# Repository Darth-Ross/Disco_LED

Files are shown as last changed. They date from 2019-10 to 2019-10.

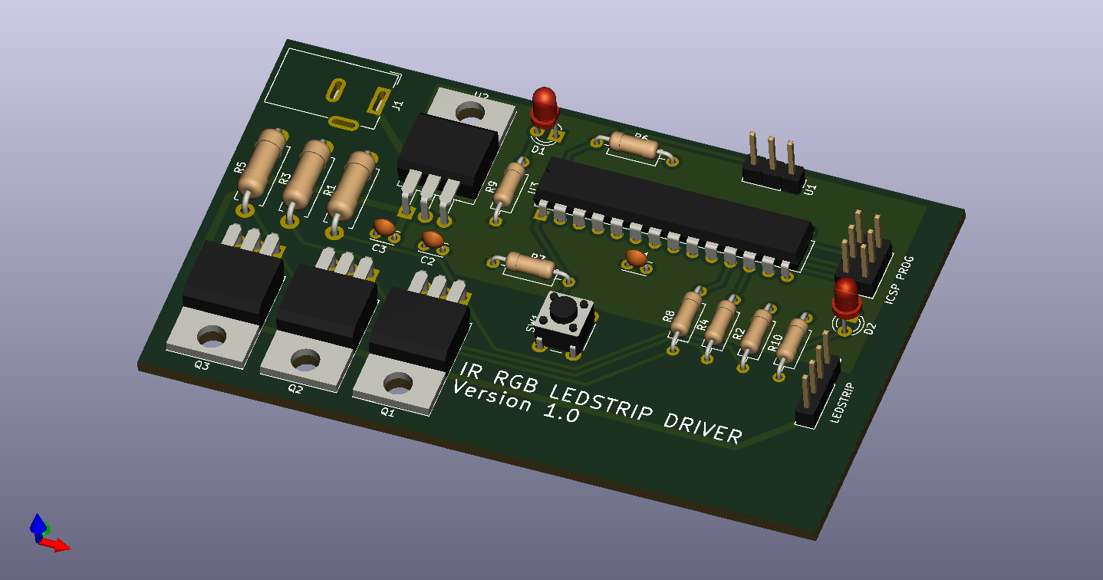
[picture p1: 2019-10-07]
Hardware/PCB/Renders/PCB_RENDER_ISOMETRIC.png

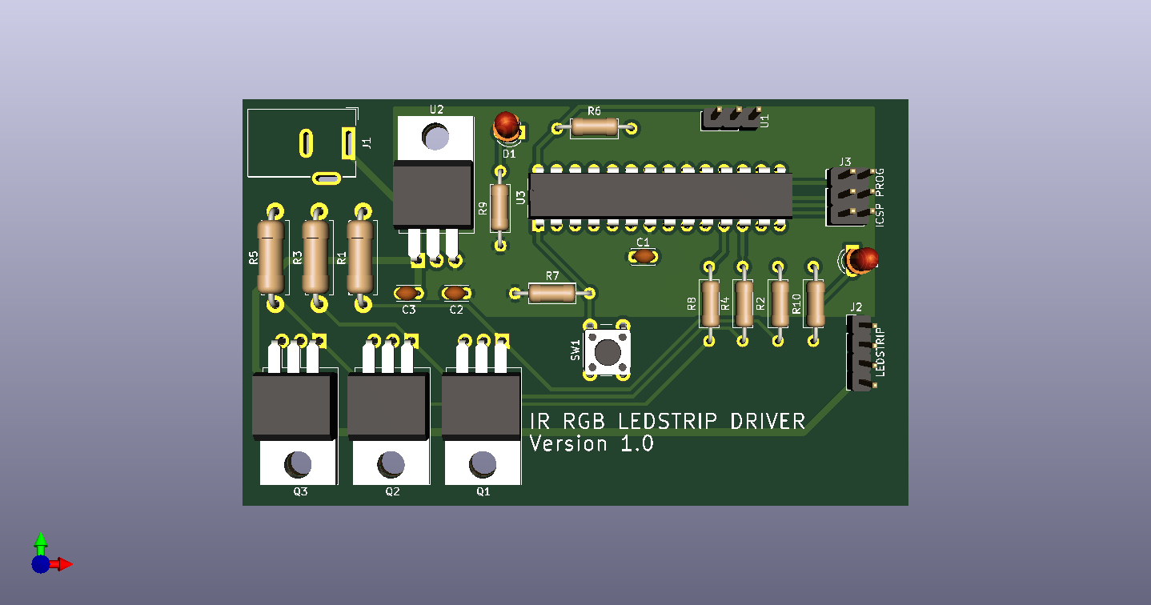
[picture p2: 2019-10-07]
Hardware/PCB/Renders/PCB_RENDER_TOP.png

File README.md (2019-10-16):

# Quick description 

This is a design for a IR RGB LEDstrip driver which uses a 24 key RGB remote. It can display 16 predetermined static colours, change brightness, turn off and on again while remembering the last colour and display special functions like for example smooth colour change or colour flashing. 

The repo includes both hardware and software design which you can either use directly or include in your own projects.

# Licenses

The software is licensed under the GNU General Public License V3.0 and the hardware is licensed under the CERN Open Hardware License V1.2. See the license files in each folder for more information.

# Libraries 

These are all the libraries I have used that were made by other users.
- https://github.com/electrobs/AVR-LIBRARY-IR_REMOTE_RECV

# Hardware changelog
#### V1.0
- Added electrical schematic
- Added PCB design
- Added licensing
#### V1.0.1
- Added gerber files 
- Added 3D renders 
#### V1.1
- Fixed connection error for ICSP port

# Software changelog
#### V1.0
- Basic feature implementation
- Added 24 key RGB remote support
- Added ATmega328p support
- Added licensing
#### V1.1
- Added first implementation of CMD_REPEAT functionality
- Reworked the brightness system to use percentage instead of RGB values. 

#### Known bugs
- CMD_REPEAT remembers the command BPLUS OR BMIN even after pressing other commands. This will cause the BPLUS or BMIN command to be executed if other commands are repeated.

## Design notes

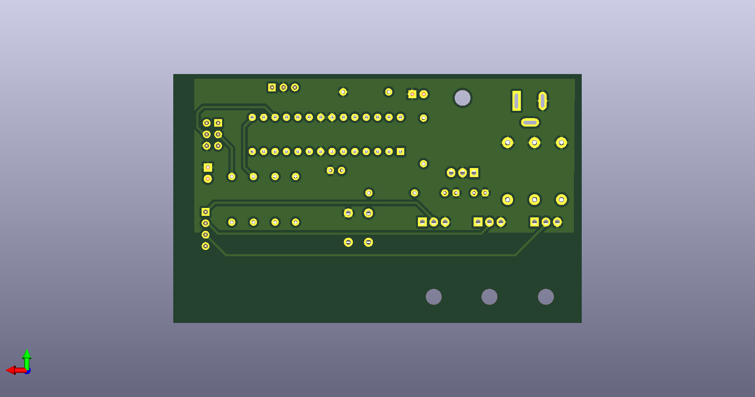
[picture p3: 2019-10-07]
Hardware/PCB/Renders/PCB_RENDER_BOTTOM.png

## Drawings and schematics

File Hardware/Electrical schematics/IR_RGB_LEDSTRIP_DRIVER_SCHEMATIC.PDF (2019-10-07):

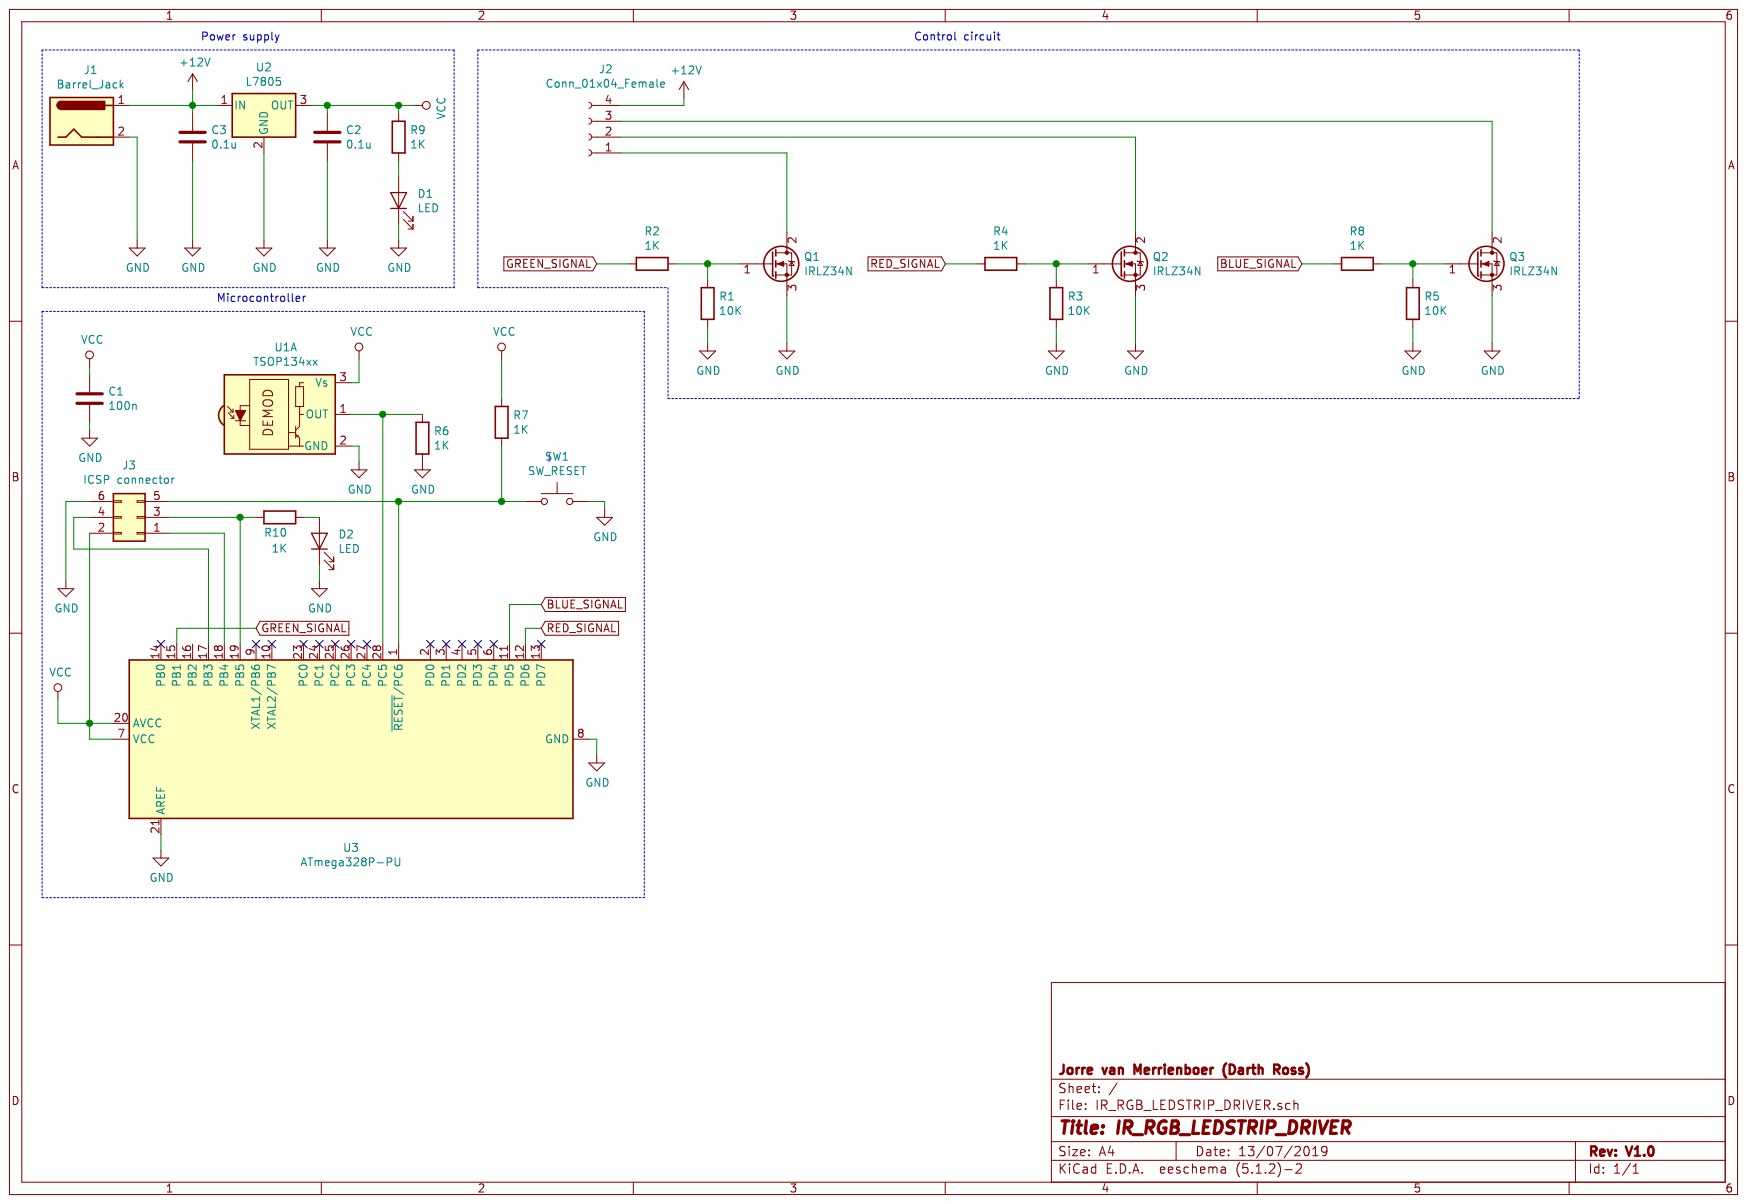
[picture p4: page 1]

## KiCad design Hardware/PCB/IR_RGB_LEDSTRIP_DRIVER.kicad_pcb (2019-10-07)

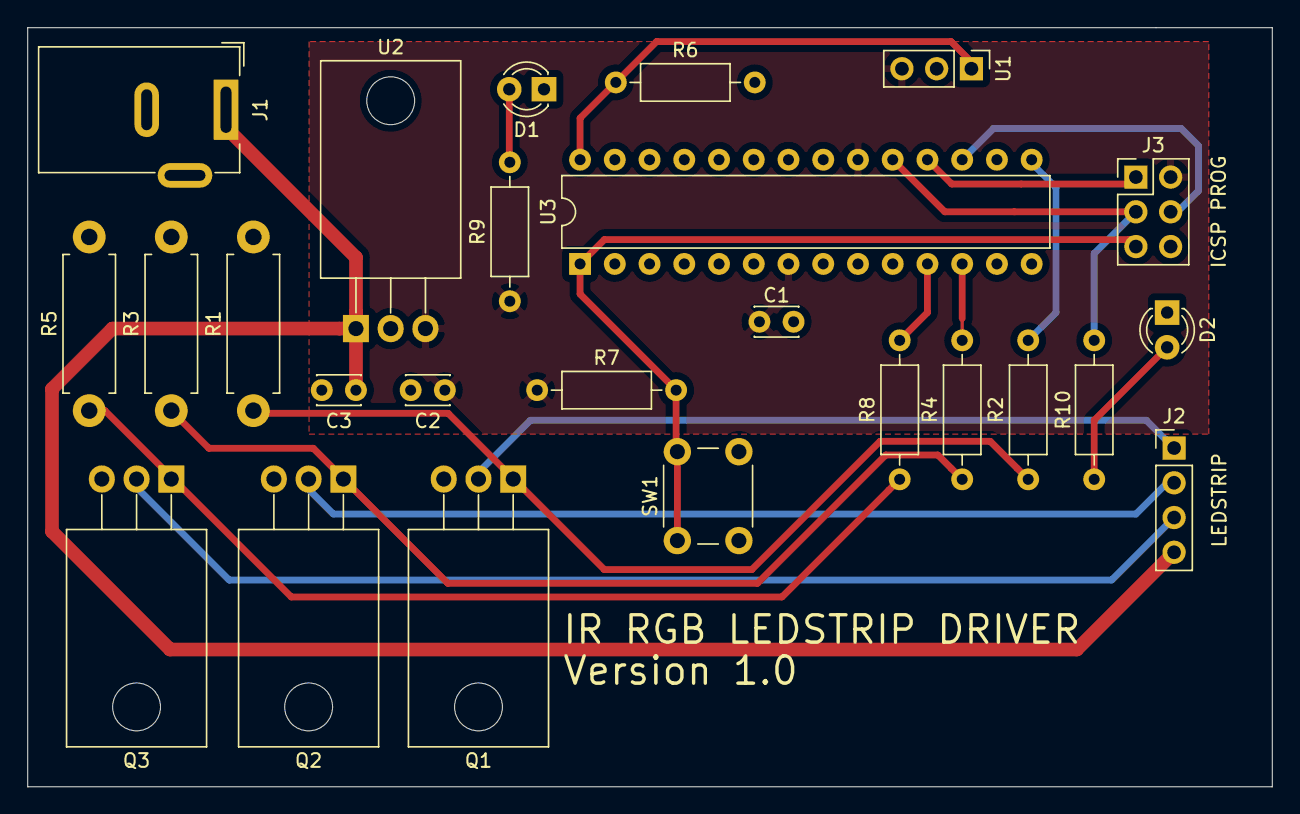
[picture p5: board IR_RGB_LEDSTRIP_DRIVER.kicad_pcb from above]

Board: 2 copper layers, 91.0 x 55.5 mm, 25 parts (0 on the bottom side), 19 nets.

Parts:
C1: 100n; C_Disc_D3.0mm_W2.0mm_P2.50mm
C2, C3: 0.1u; C_Disc_D3.0mm_W2.0mm_P2.50mm
D1, D2: LED; LED_D3.0mm
J1: Barrel_Jack; BarrelJack_Wuerth_6941xx301002
J2: Conn_01x04_Female; PinHeader_1x04_P2.54mm_Vertical
J3: ICSP connector; PinHeader_2x03_P2.54mm_Vertical
Q1, Q2, Q3: IRLZ34N; TO-220-3_Horizontal_TabDown
R1, R3, R5: 10K; R_Axial_DIN0411_L9.9mm_D3.6mm_P12.70mm_Horizontal
R2, R4, R6, R7, R8, R9, R10: 1K; R_Axial_DIN0207_L6.3mm_D2.5mm_P10.16mm_Horizontal
SW1: SW_RESET; SW_PUSH_6mm_H5mm
U1: TSOP134xx; PinHeader_1x03_P2.54mm_Vertical
U2: L7805; TO-220-3_Horizontal_TabDown
U3: ATmega328P-PU; DIP-28_W7.62mm

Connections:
+12V: C3.1, J1.1, J2.4, U2.1
BLUE_SIGNAL: R8.2, U3.11
GND: C1.2, C2.2, C3.2, D1.1, D2.1, J1.2, J3.6, Q1.3, Q2.3, Q3.3, R1.2, R3.2, R5.2, R6.2, SW1.2, U1.2, U2.2, U3.8, U3.21, U3.22
GREEN_SIGNAL: R2.2, U3.15
unnamed: D1.2, R9.2
unnamed: D2.2, R10.2
unnamed: J2.1, Q1.2
unnamed: J2.2, Q2.2
unnamed: J2.3, Q3.2
unnamed: J3.1, U3.18
unnamed: J3.3, R10.1, U3.19
unnamed: J3.4, U3.17
unnamed: J3.5, R7.2, SW1.1, U3.1
unnamed: Q1.1, R1.1, R2.1
unnamed: Q2.1, R3.1, R4.1
unnamed: Q3.1, R5.1, R8.1
unnamed: R6.1, U1.1, U3.28
RED_SIGNAL: R4.2, U3.12
VCC: C1.1, C2.1, J3.2, R7.1, R9.1, U1.3, U2.3, U3.7, U3.20

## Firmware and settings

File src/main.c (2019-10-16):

/*
* prototype.c
*
* Created: 21-2-2018 20:30:53
*  Author: Jorre
*/

#define F_CPU 8000000UL

//AVR-libraries
#include <avr/io.h>
#include <avr/interrupt.h>
#include <util/delay.h>

//Function-libraries
#include <disco_functions.h>
#include <irremote.h>
#include <remotes.h>
#include <commonTimer.h>

int main(void) 
{
	initialiseATmega328P();
	initIR(5, RGB_REMOTE_ADDRESS, RGB_REMOTE);
	init100usTimer2(F_CPU);
	
	commandAction command = NO_ACTION;
	
	brightness_Percentage = 100;
	
	red_Value = 0;
	green_Value = 0;
	blue_Value = 0;
	
	while(1) 
	{							
		command = getIRCommandRec();
		executeCommand(command);
		displayRGB(red_Value, green_Value, blue_Value);	
	}
	
	return 1;
} 

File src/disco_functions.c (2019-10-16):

/*
 * Disco_Functions.c
 *
 * Created: 30-1-2018 1:33:41
 *  Author: Jorre van Merrienboer
 */ 

#define F_CPU 8000000UL

// AVR-libraries
#include <avr/io.h>
#include <avr/common.h>
#include <util/delay.h>

// Function-libraries
#include <disco_functions.h>
#include <irremote.h>


void initialiseATmega328P(void)
{
	/////////
	// I/0 //
	/////////

	DDRD = 0xFF;				// Set PORT D as output
	DDRB = 0xFF;				// Set PORT B as output
	
	PORTD = 0;					// Set PORT D to 0
	PORTB = 0;					// Set PORT B to 0

	/////////////
	// Timer 0 //
	/////////////

	/* Set waveform generation mode to fast PWM */
	TCCR0A |= (1 << 0);			// Set WGM00 to 1
	TCCR0A |= (1 << 1);			// Set WGM01 to 1
	TCCR0B &= ~(1 << 3);		// Set WGM02 to 0
	
	/* Set compare output mode A to inverting */
	TCCR0A |= (1 << 6);			// Set COM0A0 to 1
	TCCR0A |= (1 << 7);			// Set COM0A1 to 1
	
	/* Set compare output mode B to inverting */
	TCCR0A |= (1 << 4);			// Set COM0B0 to 1
	TCCR0A |= (1 << 5);			// Set COM0B1 to 1
	
	/* Setting prescaler to 64, PWM frequency is around 1kHz */
	TCCR0B |= (1 << 0);			// Set CS00 to 1
	TCCR0B |= (1 << 1);			// Set CS01 to 1
	TCCR0B &= ~(1 << 2);		// Set CS02 to 0
	
	/////////////
	// Timer 1 //
	/////////////
	
	/* Set waveform generation mode to fast PWM 8 bit */
	TCCR1A |= (1 << 0);			// Set WGM10 to 1
	TCCR1A &= ~(1 << 1);		// Set WGM11 to 0
	
	TCCR1B |= (1 << 3);			// Set WGM12 to 1
	TCCR1B &= ~(1 << 4);		// Set WGM13 to 0
	
	/* Set compare output mode A to inverting */
	TCCR1A |= (1 << 6);			// Set COM1A0 to 1
	TCCR1A |= (1 << 7);			// Set COM1A1 to 1
	
	/* Setting prescaler to 64, PWM frequency is around 1kHz */
	TCCR1B |= (1 << 0);			// Set CS10 to 1
	TCCR1B |= (1 << 1);			// Set CS11 to 1
	TCCR1B &= ~(1 << 2);		// Set CS12 to 0
	
	/////////////
	// General //
	///////////// 
	
	TCNT0 = 0;
	TCNT1 = 0;
	
	PORTB |= (1 << 3);			// Turn on successful initialization LED. 
}

void displayRGB(char red, char green, char blue) 
{
	char PWM_RED;
	char PWM_GREEN;
	char PWM_BLUE;
	
	PWM_RED = 255 - ((red / 100) * brightness_Percentage);
	PWM_GREEN = 255 - ((green / 100) * brightness_Percentage);
	PWM_BLUE = 255 - ((blue / 100) * brightness_Percentage);	

	OCR0A = PWM_RED;
	OCR1A = PWM_GREEN;
	OCR0B = PWM_BLUE;
}

void testRGB(void) 
{
		displayRGB(255,0,0);
		_delay_ms(500);
		displayRGB(255,128,0);
		_delay_ms(500);
		displayRGB(255,255,0);
		_delay_ms(500);
		displayRGB(128,255,0);
		_delay_ms(500);
		displayRGB(0,255,128);
		_delay_ms(500);
		displayRGB(0,255,255);
		_delay_ms(500);
		displayRGB(0,128,255);
		_delay_ms(500);
		displayRGB(0,0,255);
		_delay_ms(500);
		displayRGB(127,0,255);
		_delay_ms(500);
		displayRGB(255,0,255);
		_delay_ms(500);
		displayRGB(255,0,127);
		_delay_ms(500);
		displayRGB(128,128,128);
		_delay_ms(500);
		displayRGB(0,0,0);
}

// Make safety for underflow or overflow
void brightness(char select)
{
	if(select == 1)
	{
		brightness_Percentage += 5;
		if(brightness_Percentage >= 100)	//Overflow protection 
		{
			brightness_Percentage = 100;
		}	
	}
	else
	{
		brightness_Percentage -= 5;
		if(brightness_Percentage <= 1)		//Underflow protection
		{
			brightness_Percentage = 1;	
		}
	}
}

void powerOff(void)
{
	commandAction command;
	displayRGB(0,0,0);
	
	while(command != ON)
	{
		command = getIRCommandRec();
	}
}

void ledFLASH(void)
{

}

void executeCommand(commandAction command) 
{
	if(command == CMD_REPEAT)
	{
		command = previous_Command;
	}

	switch(command) 
	{
		case OFF:
			powerOff();
			break;
	
		case BPLUS:
			brightness(1);
			previous_Command = command;
			break;
		
		case BMIN:
			brightness(0);
			previous_Command = command;
			break;
		
		case FLASH:
			// Create function
			ledFLASH();
			break;
		
		case STROBE:
			testRGB();
			break;
		
		case FADE:
			// Create function
			break;
		
		case SMOOTH:
			// Create function
			break;
			
			// Red
		case R:
			red_Value = 255;
			green_Value = 0;
			blue_Value = 0;
			break;
			
			// Green
		case G:
			red_Value = 0;
			green_Value = 255;
			blue_Value = 0;
			break;
			
			// Blue
		case B:
			red_Value = 0;
			green_Value = 0;
			blue_Value = 255;
			break;
			
			// White
		case W:
			red_Value = 255;
			green_Value = 255;
			blue_Value = 255;
			break;
				
			// Orange-red
		case B1:
			red_Value = 255;
			green_Value = 64;
			blue_Value = 0;
			break;
		 
			// Green-blue
		case B2:
			red_Value = 0;
			green_Value = 255;
			blue_Value = 64;
			break;
		
			// Blue-red
		case B3:
			red_Value = 64;
			green_Value = 255;
			blue_Value = 0;
			break;
		
			// Orange
		case B4:
			red_Value = 255;
			green_Value = 128;
			blue_Value = 0;
			break;
		
			// Cyan 3
		case B5:
			red_Value = 0;
			green_Value = 255;
			blue_Value = 128;
			break;
		
			// Purple 1
		case B6:
			red_Value = 128;
			green_Value = 0;
			blue_Value = 255;
			break;
		
			// Orange 2
		case B7:
			red_Value = 255;
			green_Value = 191;
			blue_Value = 0;
			break;	
		
			// Cyan 2
		case B8:
			red_Value = 0;
			green_Value = 255;
			blue_Value = 191;
			break;
		
			// Purple 2
		case B9:
			red_Value = 191;
			green_Value = 0;
			blue_Value = 255;
			break;
		
			//	Yellow
		case B10:
			red_Value = 255;
			green_Value = 255;
			blue_Value = 0;
			break;
		
			// Cyan 1
		case B11:
			red_Value = 0;
			green_Value = 255;
			blue_Value = 255;
			break;
		
			// Magenta
		case B12:
			red_Value = 255;
			green_Value = 0;
			blue_Value = 255;
			break;
			
		default:
			break;	
	}
}

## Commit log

2018-02-21 Initial prototype function commit
    Commition for the first function prototype.
2018-02-21 Revert "Initial commit v2"
    This reverts commit dc25a86f87c63cb3420241aa34d9152f8fef500c.
    [disco_functions.c]
2018-02-22 Prototype RGB function
2018-02-22 Revert "Prototype RGB function"
    This reverts commit 518bd678ab81e604af471f3ae03ca95bfdcec0f7.
    [disco_functions.c]
2018-02-22 Added prototype function RGB
2018-04-15 New pwm function prototype 1.
2018-04-16 Added RGB function prototype v0.1
2019-07-11 Adding first software prototype
2019-07-20 Added hardeware design
    [IR_RGB_LEDSTRIP_DRIVER.kicad_pcb, IR_RGB_LEDSTRIP_DRIVER.sch]
2019-07-22 Added PCB gerbers and renders
    [IR_RGB_LEDSTRIP_DRIVER-B_Cu.gbr, IR_RGB_LEDSTRIP_DRIVER-B_Mask.gbr, IR_RGB_LEDSTRIP_DRIVER-B_SilkS.gbr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]
2019-08-01 added the kicad file for the PCB design and added some comments to disco_functions
    [IR_RGB_LEDSTRIP_DRIVER.kicad_pcb]
2019-08-31 Added OK LED to check if the microcontroller is working OK
2019-10-07 Fixed connection error for the ICSP port
    [IR_RGB_LEDSTRIP_DRIVER-B_Cu.gbr, IR_RGB_LEDSTRIP_DRIVER-B_Mask.gbr, IR_RGB_LEDSTRIP_DRIVER-B_SilkS.gbr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]
